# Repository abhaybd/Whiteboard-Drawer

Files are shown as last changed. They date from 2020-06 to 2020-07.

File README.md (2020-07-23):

# Whiteboard-Drawer
Robot powered by an arduino that can draw on a whiteboard.

Written to accept arbitrary G-Code, which means it can draw pretty much anything.

The code for the robot is in `drawer`, and the code to calibrate the servo is in `servo_calibration`. There is also Java code that will stream a G-Code file over serial to the robot, which allows it to draw arbitrary designs.
For the most part, this robot adheres to the guidelines/rules of G-Code, and behaves like a CNC machine.



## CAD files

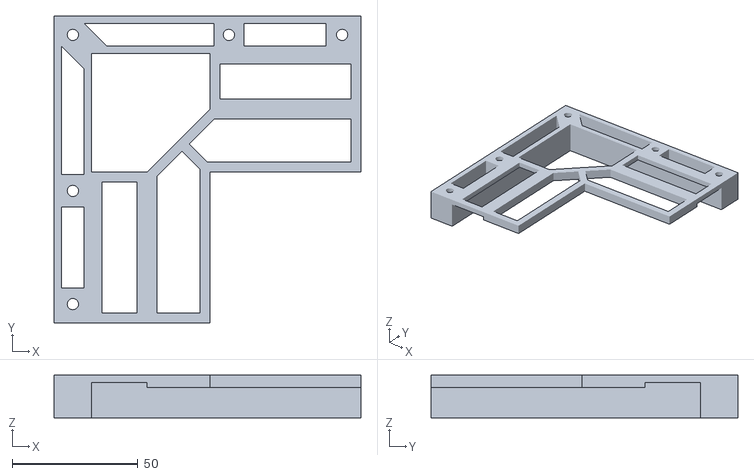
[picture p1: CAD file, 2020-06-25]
CAD/Front plate.stl
122.0 x 122.0 x 17.0

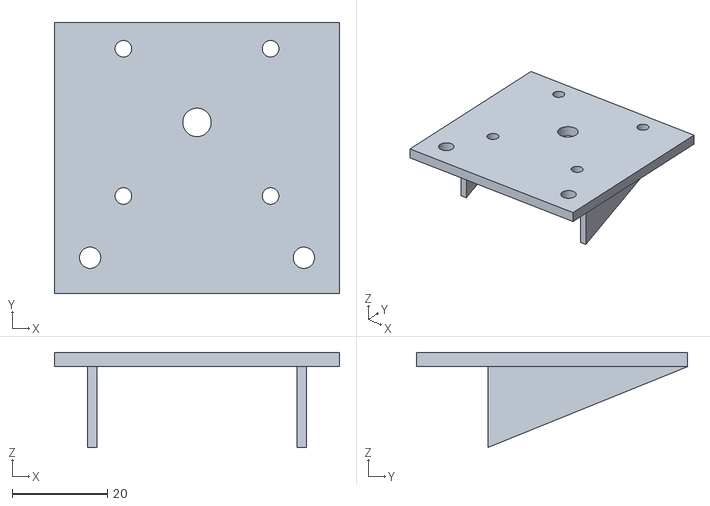
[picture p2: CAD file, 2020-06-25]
CAD/Stepper plate.stl
60.0 x 57.0 x 20.0

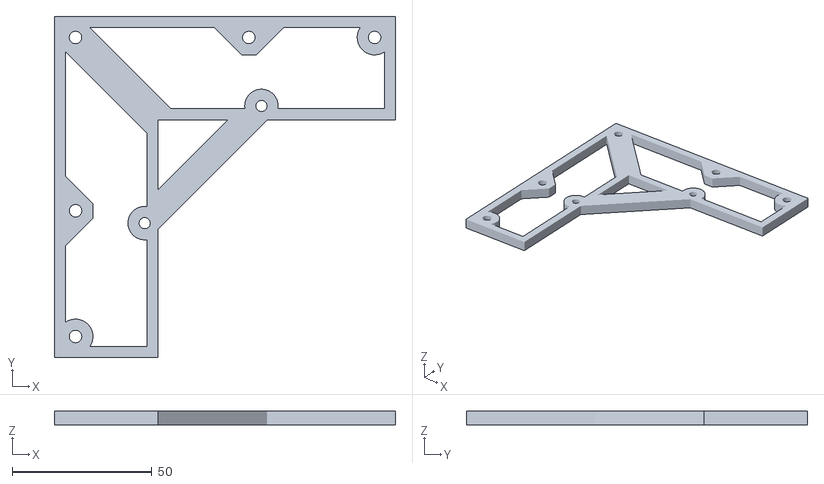
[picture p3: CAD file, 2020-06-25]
CAD/Back plate.stl
122.1 x 122.0 x 5.00

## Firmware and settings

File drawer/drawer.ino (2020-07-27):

#define PI 3.1415926535897932384626433832795

#include <Wire.h>
#include <Adafruit_MotorShield.h>
#include <AccelStepper.h>
#include <MultiStepper.h>
#include <Servo.h>

typedef float coord_t;

const int TOOL_PIN = 10;
const int TOOL_DOWN_POS = 90;
const int TOOL_UP_POS = 25;
const int TOOL_WAIT_MS = 100;
int toolPos = TOOL_UP_POS;

const float SPOOL_RAD = 7.5; // in mm
const int TICKS_PER_ROT = 200;
const float TICKS_PER_MM = TICKS_PER_ROT / (2 * PI * SPOOL_RAD);

// All of these in mm
const coord_t LEFT_X = 0;
const coord_t LEFT_Y = 400;//953;
const coord_t RIGHT_X = 660;
const coord_t RIGHT_Y = LEFT_Y;

// Also in mm
const coord_t OFFSET_X = 41.5;
const coord_t OFFSET_Y = 40;

const coord_t HOME_X = (LEFT_X + RIGHT_X) / 2;
const coord_t HOME_Y = RIGHT_Y / 2;

const coord_t MAX_SEG_LEN = 5;

const long DEF_VEL = static_cast<long>(10 * TICKS_PER_MM); // in ticks per second

Adafruit_MotorShield shield;
Adafruit_StepperMotor *leftStepper = shield.getStepper(TICKS_PER_ROT, 1);
Adafruit_StepperMotor *rightStepper = shield.getStepper(TICKS_PER_ROT, 2);

Servo tool;

AccelStepper left([]() {
    leftStepper->onestep(FORWARD, SINGLE);
}, []() {
    leftStepper->onestep(BACKWARD, SINGLE);
});
AccelStepper right([]() { // this is inverted to invert the motor
    rightStepper->onestep(BACKWARD, SINGLE);
}, []() {
    rightStepper->onestep(FORWARD, SINGLE);
});

MultiStepper ms;

/**
    Calculates the target position of each stepper, in units of steps. x and y are in mm.
*/
void calculateTargetSteps(coord_t x, coord_t y, long& l1, long& l2) {
    l1 = static_cast<long>(hypot(x - OFFSET_X - LEFT_X, y + OFFSET_Y - LEFT_Y) * TICKS_PER_MM);
    l2 = static_cast<long>(hypot(x + OFFSET_X - RIGHT_X, y + OFFSET_Y - RIGHT_Y) * TICKS_PER_MM);
}

/**
    Calculates the current position of the marker, in units of mm
*/
void getPosition(coord_t& x, coord_t& y) {
    float l1 = left.currentPosition() / TICKS_PER_MM; // length of left cord
    float l2 = right.currentPosition() / TICKS_PER_MM; // length of right cord

    coord_t o = OFFSET_X * 2; // distance between anchor points
    coord_t w = RIGHT_X - LEFT_X; // width of whiteboard

    // derived from geometry/math
    float leftAnchorX = (sq(l1) - sq(l2) + sq(o) + sq(w) - 2 * o * w) / (2 * (w - o));
    float leftAnchorY = LEFT_Y - sqrt(sq(l1) - sq(leftAnchorX));

    x = static_cast<coord_t>(leftAnchorX + OFFSET_X);
    y = static_cast<coord_t>(leftAnchorY - OFFSET_Y);
}

void moveBothTo(long l, long r) {
    long positions[] = {l, r};
    ms.moveTo(positions);
    ms.runSpeedToPosition();
}

void zero() {
    left.setCurrentPosition(0);
    right.setCurrentPosition(0);

    long l, r;
    calculateTargetSteps(HOME_X, HOME_Y, l, r);
    Serial.println("// Homing...");
    moveBothTo(l, r);
}

float arcLength(coord_t currX, coord_t currY, coord_t x, coord_t y, float curvature) {
    float dx = x - currX;
    float dy = y - currY;

    if (curvature == 0) return hypot(dx, dy);
    else {
        float dist = hypot(dx, dy);
        float angle = 2 * asin(dist * curvature / 2);
        return angle / curvature;
    }
}

void interpolate(float t, coord_t currX, coord_t currY, coord_t targetX, coord_t targetY, float curvature, bool clockwise, coord_t& interpX, coord_t& interpY) {
    if (curvature == 0) {
        // If this is a line, interpolation is easy peasy
        interpX = currX + t * (targetX - currX);
        interpY = currY + t * (targetY - currY);
    } else {
        // Get vector from current to target
        float dx = targetX - currX;
        float dy = targetY - currY;
        float dist = hypot(dx, dy);

        // normalize that vector
        float dxNorm = dx / dist;
        float dyNorm = dy / dist;

        // This is the distance between the circle center and the chord
        float d = sqrt(sq(1 / curvature) - sq(dist / 2));

        // Calculate the circle center (find midpoint between curr and target and add normalized vector rotated CW or CCW 90 deg and scaled by d)
        float cX, cY;
        if (clockwise) {
            cX = currX + dx / 2 + dyNorm * d;
            cY = currY + dy / 2 - dxNorm * d;
        } else {
            cX = currX + dx / 2 - dyNorm * d;
            cY = currY + dy / 2 + dxNorm * d;
        }

        // Get vector from circle center to current position
        float fromCX = currX - cX;
        float fromCY = currY - cY;
        // This is the angle subtended by the chord from current to target
        float angle = 2 * asin(dist * curvature / 2) * t;
        if (!clockwise) angle = -angle; // Negative angle means CCW
        // Apply a CW rotation by angle (if angle < 0 then rotation is CCW)
        float x = cos(angle) * fromCX + sin(angle) * fromCY;
        float y = -sin(angle) * fromCX + cos(angle) * fromCY;
        // Add back to circle center to get interpolated point
        interpX = cX + x;
        interpY = cY + y;
    }
}

void setPosition(coord_t x, coord_t y, float curvature, bool clockwise) {
    coord_t currX, currY;
    getPosition(currX, currY); // get the current position
    float arcLen = arcLength(currX, currY, x, y, curvature);
    int numSegs = ceil(arcLen / MAX_SEG_LEN); // calculate the number of sub-segments to use based on arc length
    Serial.print("// ArcLen=");
    Serial.print(arcLen);
    Serial.print(", numSegs=");
    Serial.println(numSegs);
    // Step along each segment
    for (int i = 0; i < numSegs; i++) {
        float t = static_cast<float>(i + 1) / numSegs;
        coord_t interpX, interpY;
        interpolate(t, currX, currY, x, y, curvature, clockwise, interpX, interpY); // calculate target x and y positions
        long left, right;
        calculateTargetSteps(interpX, interpY, left, right); // from x and y positions, calculate target motor steps
        moveBothTo(left, right); // move both motors uncoordinatedly
    }
}

void setToolUp(bool up) {
    int target = up ? TOOL_UP_POS : TOOL_DOWN_POS;
    // If we're not already at the target position, set it now
    if (target != toolPos) {
        toolPos = target;
        tool.write(target);
        delay(TOOL_WAIT_MS); // delay to give the servo time to get there
    }
}

void printCurrentPos() {
    coord_t x, y;
    getPosition(x, y);
    Serial.print("// X:");
    Serial.print(x);
    Serial.print(" Y:");
    Serial.print(y);
    Serial.print(" Z:");
    Serial.println(toolPos == TOOL_UP_POS ? 1 : -1);
    long l = left.currentPosition(); // length of left cord
    long r = right.currentPosition(); // length of right cord
    Serial.print("// L:");
    Serial.print(l);
    Serial.print(" R:");
    Serial.println(r);
}

void setup() {
    Serial.begin(9600);
    shield.begin();
    tool.attach(TOOL_PIN);

    toolPos = TOOL_UP_POS;
    tool.write(toolPos);

    left.setAcceleration(DEF_VEL * 2);
    right.setAcceleration(DEF_VEL * 2);
    left.setMaxSpeed(DEF_VEL);
    right.setMaxSpeed(DEF_VEL);

    ms.addStepper(left);
    ms.addStepper(right);

    Serial.println("// Hello world!");
}

coord_t targetX = HOME_X;
coord_t targetY = HOME_Y;
coord_t targetZ = 0;

#define numParts 6
#define commandLen 100
void loop() {
    // wait for data to become available
    while (Serial.available() == 0) {
        delay(10);
    }

    // read command from serial
    char command[commandLen] = {};
    size_t len = Serial.readBytesUntil('\n', command, commandLen - 1);
    command[len] = '\0'; // make sure string is null terminated

    // Tokenize into space delimited parts
    char* parts[numParts] = {};
    char* part = strtok(command, " \n");
    for (size_t i = 0; i < numParts && part != nullptr; i++) {
        parts[i] = part;
        part = strtok(nullptr, " \n");
    }

    // Execute g-code command
    char* type = parts[0];
    if (type == nullptr) {
        Serial.println("// Empty command! Failing silently...");
    } else if (strcmp(type, "G28") == 0) { // If it's a home command
        targetX = HOME_X;
        targetY = HOME_Y;
        targetZ = 0;
        setToolUp(true);
        zero();
    } else if (type[0] == 'G') {
        coord_t arcI = 0;
        coord_t arcJ = 0;
        for (int i = 1; i < numParts && parts[i] != nullptr; i++) {
            if (parts[i][0] == 'X') {
                targetX = static_cast<coord_t>(strtod(&parts[i][1], nullptr));
            } else if (parts[i][0] == 'Y') {
                targetY = static_cast<coord_t>(strtod(&parts[i][1], nullptr));
            } else if (parts[i][0] == 'Z') {
                targetZ = static_cast<coord_t>(strtod(&parts[i][1], nullptr));
            } else if (parts[i][0] == 'I') {
                arcI = static_cast<coord_t>(strtod(&parts[i][1], nullptr));
            } else if (parts[i][0] == 'J') {
                arcJ = static_cast<coord_t>(strtod(&parts[i][1], nullptr));
            }
        }
        if (targetX < OFFSET_X + 5) { // Clamp to prevent invalid x target
            targetX = OFFSET_X + 5;
        }
        setToolUp(targetZ >= 0);
        long code = strtol(&type[1], nullptr, 10);
        if (code == 0 || code == 1) {
            setPosition(targetX, targetY, 0, false);
        } else if (code == 2 || code == 3) {
            if (arcI != 0 || arcJ != 0) {
                float rad = hypot(arcI, arcJ);
                setPosition(targetX, targetY, 1 / rad, code == 2);
            } else {
                Serial.println("// Invalid G2/G3 command!");
                Serial.println("!!");
                return;
            }
        } else {
            Serial.print("// Unsupported g-code: G");
            Serial.println(code);
        }
    } else if (type[0] == 'M') {
        long code = strtol(&type[1], nullptr, 10);
        if (code == 118) {
            printCurrentPos();
            coord_t x, y;
            getPosition(x, y);
            Serial.print("ok X:");
            Serial.print(x);
            Serial.print(" Y:");
            Serial.print(y);
            Serial.print(" Z:");
            Serial.println(toolPos == TOOL_UP_POS ? 1 : -1);
            return;
        } else if (code == 18) {
            leftStepper->release();
            rightStepper->release();
        }
    } else if (type[0] == 'L') {
        long pos = strtol(parts[1], nullptr, 10);
        moveBothTo(pos, right.currentPosition());
    } else if (type[0] == 'R') {
        long pos = strtol(parts[1], nullptr, 10);
        moveBothTo(left.currentPosition(), pos);
    } else {
        Serial.println("// Invalid command! Failing silently...");
    }

    Serial.println("ok");
}

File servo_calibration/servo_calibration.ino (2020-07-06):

#include <Servo.h>
#include <Wire.h>

/**
    This script is used to calibrate the servo used to lift and lower the tool.
    Run this script with the servo plugged in. Type different positions into the terminal, and the servo will go to that position.
    Find appropriate positions for "up" and "down", and save them.
*/

Servo servo;

void setup() {
    Serial.begin(9600);
    servo.attach(10);
}

void loop() {
    // Wait for data
    while (Serial.available() == 0) {
        delay(10);
    }

    // Read at most 4 bytes from the terminal
    char posTarget[5] = {};
    size_t len = Serial.readBytesUntil('\n', posTarget, 4);
    posTarget[len] = '\0';

    // Parse the recieved number as a long
    long target = strtol(posTarget, nullptr, 10);
    Serial.print("// Recieved target: ");
    Serial.println(target);

    // Set the target for the servo, and wait for it to reach it
    servo.write(target);
    delay(100);
}

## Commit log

2020-06-23 Added drawer and stepper test
2020-06-25 Added CAD models
    [Back plate.stl, Front plate.stl, Stepper plate.stl]
2020-06-26 Report success and failures via serial
    [drawer.ino]
2020-06-26 Print sent commands and recieved responses
2020-07-01 Testing with physical arduino! Fixed bugs
    [drawer.ino]
2020-07-02 Removed coordinated velocity
2020-07-04 Bug fixes, use multistepper for interpolated segments
    [drawer.ino]
2020-07-05 Calibrated tool servo, added hello world gcode
2020-07-05 Removed stepper test
2020-07-06 Moved CAD, added comments
    [Back plate.stl, Front plate.stl, Stepper plate.stl]
2020-07-10 Added debug statements, adjusted constants, bug fixes
    [drawer.ino]
2020-07-17 Fixed build break, added l and r debug, improved response parsing
    [drawer.ino]
2020-07-20 Added custom commands to set motor positions, playing with way of movement
2020-07-21 Fixed missed steps, added M18 command
    [drawer.ino]
2020-07-23 Removed extraneous debug statements, added shutdown hook, commented out bug
    [drawer.ino]
2020-07-23 Expanded board height
2020-07-27 Removed print position on every loop, reduced board height
